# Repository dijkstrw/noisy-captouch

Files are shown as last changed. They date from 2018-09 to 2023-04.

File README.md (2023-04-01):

Noisy captouch
==============

Toggling a lamp by touching its plastic base.

This project adds capacitive touch to an IKEA Jansjo light. An MSP430 on a
custom pcb is installed in between the lamp power supply and the lamp. The
MSP430 detects touches using a sensor pad in the base of the lamp, under the
ABS cover.

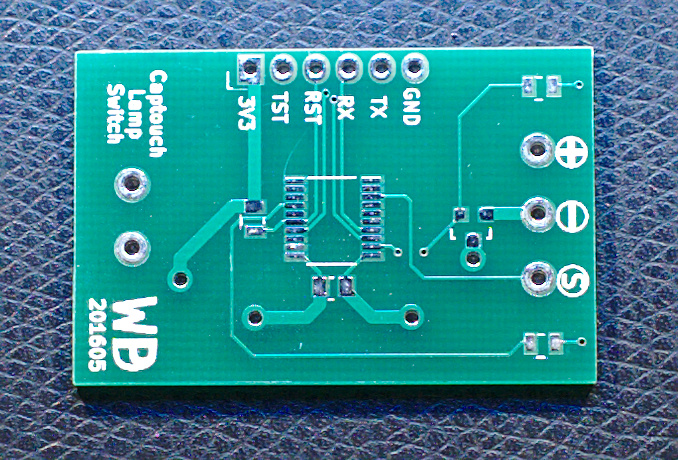
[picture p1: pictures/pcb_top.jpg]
PCB v1 Top

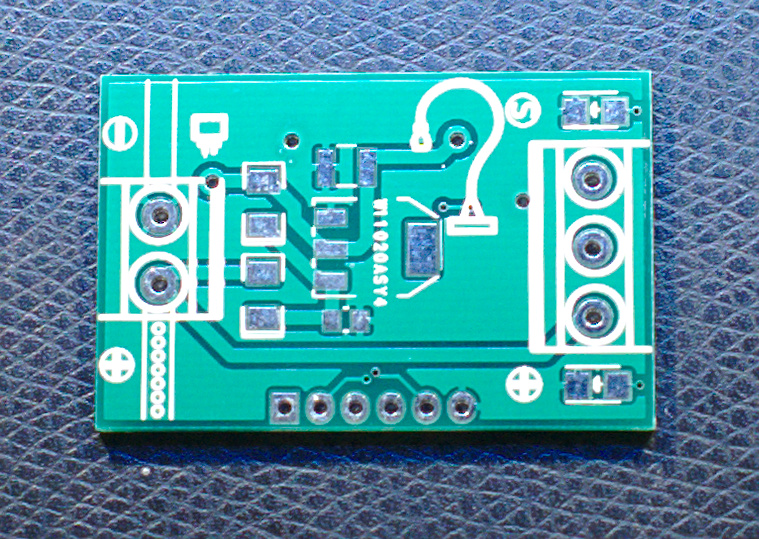
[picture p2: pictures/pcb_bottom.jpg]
PCB v1 Bottom

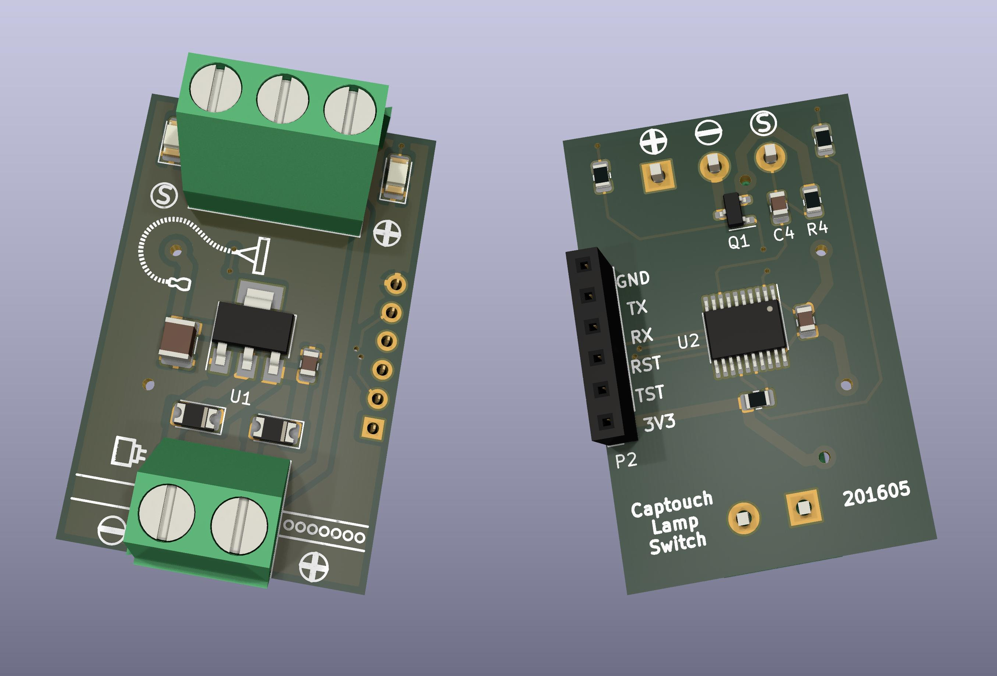
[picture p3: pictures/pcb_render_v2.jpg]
PCB v2

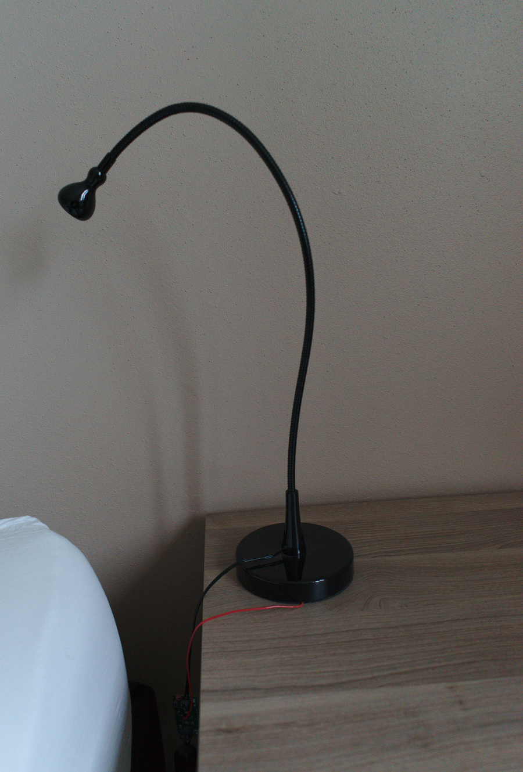
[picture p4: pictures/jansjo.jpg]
Jansjo on nightstand


Touch algorithm
---------------
The measurement happens in a number of steps:
- first we build up a sliding sample window of 16 measurements
  (sum). This also provides us with a moving average (sum/16).

- we calculate a derivative = moving average - current measurement.

- if the derivative is positive: the measurement indicates that the
  counter wrapped less times than expected; which can be an indication
  of increased capacitance due to a touch event.

- if the derivative is higher than a preset threshold (minimum
  required change) we add part of it to the integral. Note that only
  part is considered, to make sure we need multiple "positive"
  measurements in sequence before we signal a touch event.

- if the integral has reached a preset threshold we signal a touch
  event, if not, we leak away some of our integrand to make sure the
  integral reports over a recent period only.

This algorithm tries to cater for a number of things:

- Atmospheric changes will change the measured capacitance, so we must
  take measurement drift into account.

- The electrodes are very sensitive and will pickup any large enough
  emf spikes, so we cannot trust single measured capacitance changes.

- If the emf spikes are high enough almost arbitrary measurements are
  possible, so we need to limit their contribution to integrand.

Complications
-------------

1. Power for the msp430 comes from a wallwart that also feeds the
   lamp. When the lamp is off, only the msp430 is drawing
   current. When the lamp is on an additional 500mA is drawn from the
   wallwart. This transition causes unwanted powersupply noise that
   interferes with the measurements.

2. When programming and debugging the ground is connected to the
   programmer ground. The effect of point 1 can then be
   underestimated. It is best to use an usb isolator when programming.

3. There are no right values for the capacitive touch thresholds, as
   these depend on the capacitive measurement, which in turn depend on
   your touch pad geometry. Especially for home built arbitrary sized
   pads as lamp bases, the values will differ between pads.

USCI
----
By using WDT for measurement we have enough of Timer0 left to do
bitbanging serial for non-USCI MSPs. (msp430g2452).

References
----------
- [Benn Thomsen, Capacitive Touch examples, March 2016](https://github.com/bennthomsen/CapacitiveTouch)
- Brandon Elliott/D. Dang, Texas Instruments Inc., November 2010

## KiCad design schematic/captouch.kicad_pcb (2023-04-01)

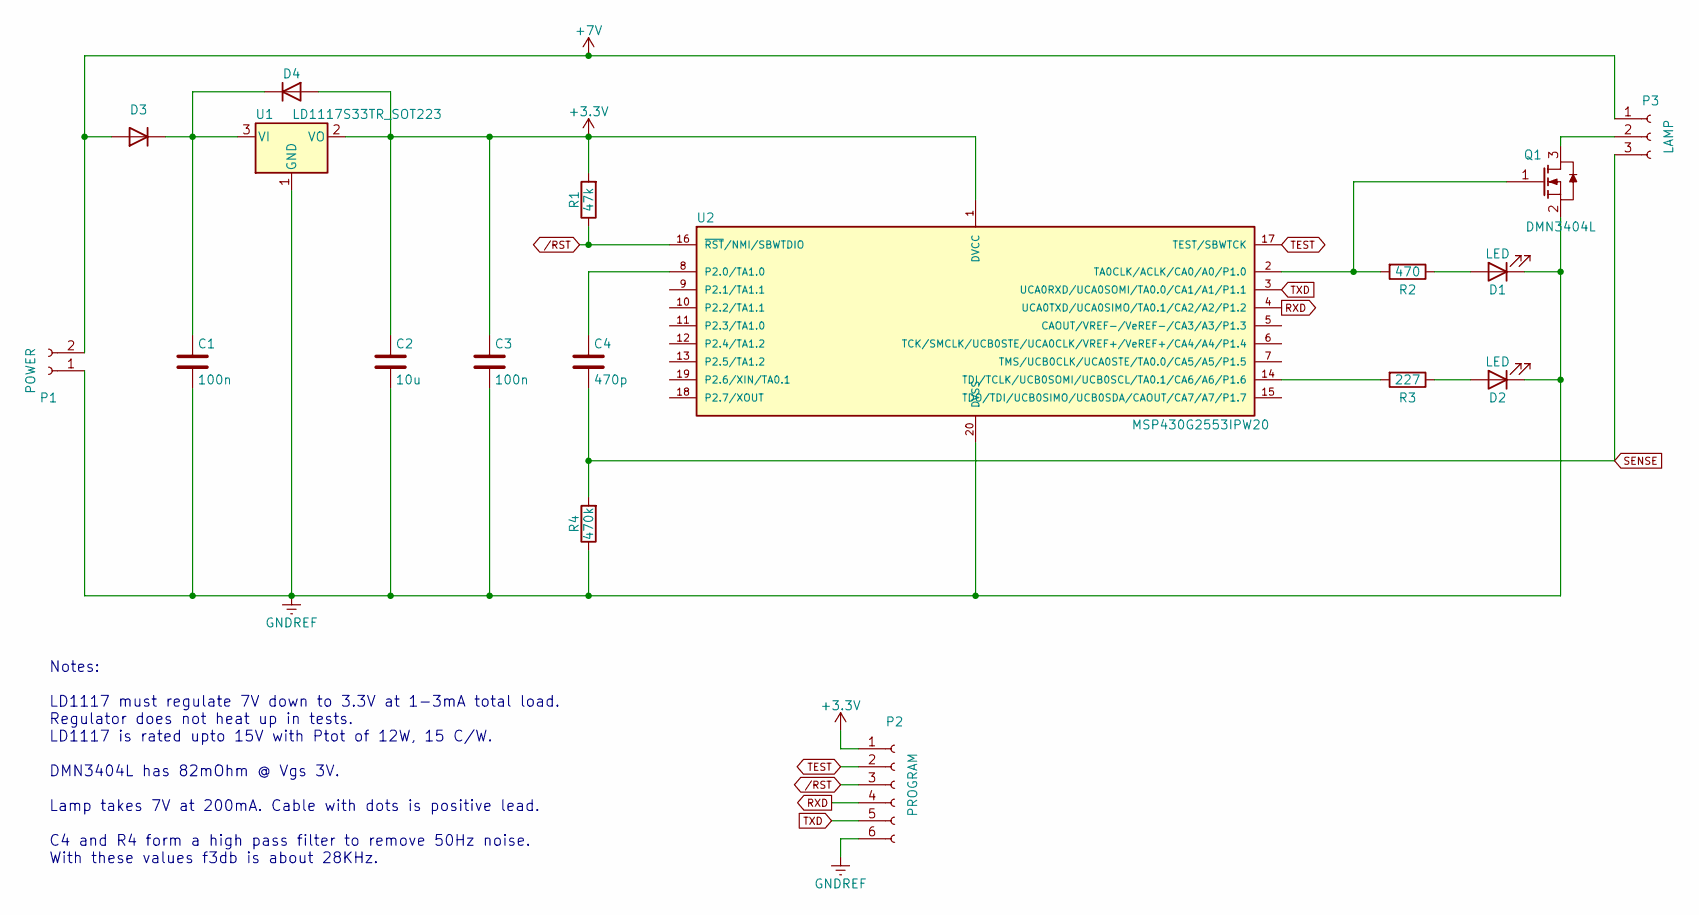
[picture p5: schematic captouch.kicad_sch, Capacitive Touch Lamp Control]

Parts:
C1, C3: 100n; C_0805
C2: 10u; C_1210
C4: 470p; C_0805
D1, D2: LED; LED_1206
D3, D4: D; SMD-1206_Pol
P1: POWER; P_1,5-2
P2: PROGRAM; Pin_Header_Angled_1x06
P3: LAMP; P_1,5-3
Q1: DMN3404L; SOT-23
R1: 47k; R_0805
R2: 470; R_0805
R3: 227; R_0805
R4: 470k; R_0805
U1: LD1117S33TR_SOT223; SOT-223-3_TabPin2
U2: MSP430G2553IPW20; TSSOP-20_4.4x6.5mm_Pitch0.65mm

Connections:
+3.3V: C2.1, C3.1, D4.2 (A), P2.1, R1.2, U1.2 (VO), U2.1 (DVCC)
+7V: D3.2 (A), P1.2, P3.1
GNDREF: C1.2, C2.2, C3.2, D1.1 (K), D2.1 (K), P1.1, P2.6, Q1.2 (S), R4.1, U1.1 (GND), U2.20 (DVSS)
unnamed: C1.1, D3.1 (K), D4.1 (K), U1.3 (VI)
unnamed: P3.2, Q1.3 (D)
unnamed: Q1.1 (G), R2.2, U2.2 (TA0CLK/ACLK/CA0/A0/P1.0)
unnamed: D1.2 (A), R2.1
unnamed: D2.2 (A), R3.1
unnamed: C4.1, U2.8 (P2.0/TA1.0)
unnamed: R3.2, U2.14 (TDI/TCLK/UCB0SOMI/UCB0SCL/TA0.1/CA6/A6/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)
RXD: P2.4, U2.4 (UCA0TXD/UCA0SIMO/TA0.1/CA2/A2/P1.2)
SENSE: C4.2, P3.3, R4.2
TEST: P2.2, U2.17 (TEST/SBWTCK)
TXD: P2.5, U2.3 (UCA0RXD/UCA0SOMI/TA0.0/CA1/A1/P1.1)
/RST: P2.3, R1.1, U2.16 (~RST/NMI/SBWTDIO)

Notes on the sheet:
Notes: LD1117 must regulate 7V down to 3.3V at 1-3mA total load. Regulator does not heat up in tests. LD1117 is rated upto 15V with Ptot of 12W, 15 C/W. DMN3404L has 82mOhm @ Vgs 3V. Lamp takes 7V at 200mA. Cable with dots is positive lead. C4 and R4 form a high pass filter to remove 50Hz noise. Wi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

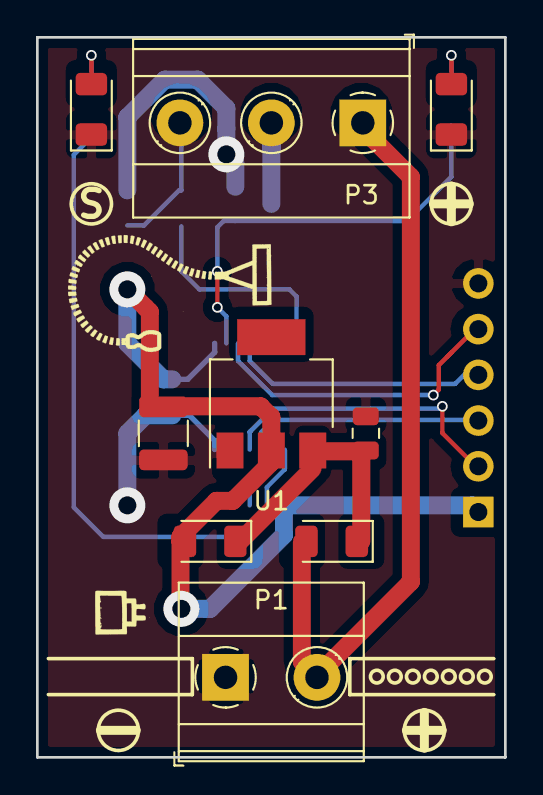
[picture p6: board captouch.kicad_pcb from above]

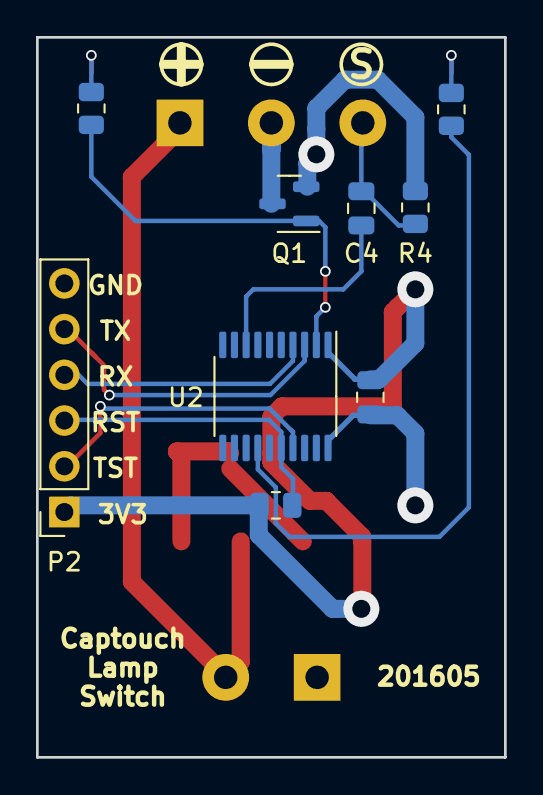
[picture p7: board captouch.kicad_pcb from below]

Board: 2 copper layers, 26.0 x 40.0 mm, 19 parts (9 on the bottom side), 15 nets.

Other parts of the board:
  : lamp

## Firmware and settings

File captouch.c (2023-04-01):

/*
 * MSP430 Capacitive Lamp Control
 *
 * Toggling a lamp by touching its plastic base.
 *
 * Description: Basic 1-button input using the built-in pin oscillation feature
 * on GPIO input structure. PinOsc signal feed into TA0CLK. WDT interval is
 * used to gate the measurements. A large difference in measurements indicate
 * button touch.
 *
 * Use an averaging window of SAMPLES as a moving baseline to compare incoming
 * "sensor" readings. This makes a large difference for touch stand out, while
 * allowing for a gradual drift to accomodate for athmospheric changes.
 *
 * ACLK = VLO = 12kHz, MCLK = SMCLK = 1MHz DCO
 *
 *               MSP430G2xxx
 *             -----------------
 *         /|\|              XIN|- UART
 *          | |                 |
 *          --|RST          XOUT|-
 *            |                 |
 *            |             P2.0|<--Capacitive Touch Input 1
 *            |                 |
 *  LED 2  <--|P1.6             |
 *  window reset indication     |
 *  LED 1  <--|P1.0             |
 *  lamp driver/indication      |
 *            |                 |
 *
 *
 * Based on source from:
 * - Benn Thomsen, March 2016
 * - Brandon Elliott/D. Dang, Texas Instruments Inc., November 2010
 */

#include <stdint.h>
#include <stdlib.h>
#include <msp430.h>
#include "captouch.h"
#include "uart.h"
#include "xprint.h"

uint8_t lamp;
uint8_t state;

uint16_t loops = 0;
int16_t on_timer = 0;
window_t window;

uint16_t
measure(uint8_t pin)
{
    uint16_t result;

    /* Ground the input */
    P2SEL &= ~pin;
    P2DIR &= ~pin;
    P2OUT &= ~pin;
    P2REN |= pin;
    P2REN &= ~pin;

    WDTCTL = WDT_GROUND_INTERVAL;
    _BIS_SR(LPM0_bits + GIE);

    /* Configure timer to capture oscillator */
    TA0CTL = TASSEL_3 + MC_2;           /* INCLK from Pin oscillator, continous count mode to 0xFFFF */
    TA0CCTL1 = CM_3 + CCIS_2 + CAP;     /* Capture on Rising and Falling Edge,Capture input GND,Capture mode */

    /*
     * Configure Ports for relaxation oscillator
     * P2SEL2 allows Timer_A to receive it's clock from a GPIO
     */
    P2DIR &= ~pin;
    P2SEL &= ~pin;
    P2SEL2 |= pin;

    /* Setup Gate Timer */
    WDTCTL = WDT_MEASURE_INTERVAL;
    TA0CTL |= TACLR;                    /* Reset timer */
    _BIS_SR(LPM0_bits + GIE);
    TA0CCTL1 ^= CCIS0;                  /* Toggle the counter capture input to capture count using TACCR1 */
    result = TACCR1;
    P2SEL2 &= ~pin;                     /* Disable Oscillator */

    WDTCTL = WDTPW + WDTHOLD;
    /* Ground the input */
    P2SEL &= ~pin;
    P2DIR &= ~pin;
    P2OUT &= ~pin;
    P2REN |= pin;
    P2REN &= ~pin;

    return result;
}

uint8_t
detect()
{
    uint16_t measurement = measure(TOUCH_PIN);

    /*
     * Keep track of how many measurements we have between emitting
     * state
     */
    window.times = window.times + 1;

    /*
     * Look at the amount of change
     */
    window.derivative = window.avg - measurement;

    /*
     * An increase of capacitance means that less full counts of the
     * oscillator will be counted; so a touch => a positive
     * derivative
     */
    if (window.derivative > DERIVATIVE_THRESHOLD) {
        window.integral += DERIVATIVE_THRESHOLD;
    } else {
        /*
         * Make current measurement part of the moving average
         */
        window.sum -= window.data[window.index];
        window.data[window.index] = measurement;
        window.sum += window.data[window.index];
        window.index = (window.index + 1 ) % SAMPLES;

        window.avg = window.sum >> SAMPLES_DIV;
    }

    /*
     * Now look at the accumulated change
     */
    if (window.integral > INTEGRAL_THRESHOLD) {
        emit_state();
        window.integral = 0;
        return 1;
    } else {
        /* No touch -- leak away some of our integrand */
        if (window.integral > LEAKAGE_FACTOR) {
            window.integral -= LEAKAGE_FACTOR;
        } else {
            window.integral = 0;
        }

        return 0;
    }
}

void
emit_state(void)
{
    xprintf("S%01x p%01x o%04x D%04x I%04x A%04x S%04x%04x t%04x \r\n",
            state,
            lamp,
            on_timer,
            window.derivative,
            window.integral,
            window.avg,
            (uint16_t )(window.sum >> 16),
            (uint16_t)(window.sum & 0xFFFF),
            window.times);
    window.times = 0;
}

void
lamp_off(void)
{
    LED_OUT &= ~LAMP_PIN;
    lamp = 0;
    emit_state();
}

void
lamp_on(void)
{
    LED_OUT |= LAMP_PIN;
    lamp = 1;
    emit_state();
}

void
reset_window()
{
    window.sum = window.derivative = window.integral = 0;

    for (window.index = 0; window.index < SAMPLES; window.index++) {
        window.data[window.index] = measure(TOUCH_PIN);
        window.sum += window.data[window.index];
        xprintf("Reset window %02x: S%04x%04x \r\n",
                window.index,
                (uint16_t )(window.sum >> 16),
                (uint16_t)(window.sum & 0xFFFF));
    }
    window.times = 0;
    window.avg = window.sum >> SAMPLES_DIV;
}

int
main(void)
{
    uint8_t touch;

    WDTCTL = WDTPW + WDTHOLD;    /* Stop WDT */
    DCOCTL = 0;                  /* Select lowest DCOx and MODx settings */
    BCSCTL1 = CALBC1_1MHZ;       /* Set DCO to 1MHz */
    DCOCTL = CALDCO_1MHZ;
    BCSCTL3 |= LFXT1S_2;         /* LFXT1 = VLO 12kHz */

    IE1 |= WDTIE;

    LED_DIR |= (LAMP_PIN + BOOT_PIN);
    LED_OUT &= ~(LAMP_PIN + BOOT_PIN);

    uart_configure();
    _BIS_SR(GIE);
    __no_operation();

    lamp = 0;
    reset_window();
    state = LAMP_RESET;

    for (;;) { /* FOREVER */
        touch = detect();

        switch (state) {
        case LAMP_RESET:
            /* 0. After boot and after a change, take one second to settle */
            LED_OUT |= BOOT_PIN;
            loops++;
            if (loops > LOOPS_1S) {
                LED_OUT &= ~BOOT_PIN;
                loops -= LOOPS_1S;
                state = LAMP_IDLE;
                reset_window();
                emit_state();
            }
            break;

        case LAMP_IDLE:
            /* 1. In idle, countdown on time or "detect" touch */
            if (lamp) {
                if (on_timer > 0) {
                    loops++;
                    while (loops > LOOPS_1S) {
                        loops -= LOOPS_1S;
                        on_timer--;
                        emit_state();
                    }
                } else {
                    lamp_off();
                }
            } else {
                on_timer = 0;
            }

            if (touch) {
                state = LAMP_ACTION;
            }
            break;

        case LAMP_ACTION:
            /* 2. Change lamp state and revert to RESET */
            lamp ^=1;
            if (lamp) {
                lamp_on();
                on_timer = AUTO_OFF_S;
            } else {
                lamp_off();
                on_timer = 0;
            }
            state = LAMP_RESET;
            loops = 0;
            break;
        }

        WDTCTL = WDT_DELAY_INTERVAL;
        LPM3;
    }
}

void __attribute__((interrupt(WDT_VECTOR))) watchdog_timer(void)
{
    LPM3_EXIT;
}

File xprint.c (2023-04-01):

/*
 * MSP430 minimal xprintf
 *
 * Based on mini-printf:
 * Copyright (c) 2013,2014 Michal Ludvig <michal@logix.cz>
 * All rights reserved.
 *
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
 * THIS SOFTWARE IS PROVIDED BY THE COPYRIGHT HOLDERS AND CONTRIBUTORS "AS IS" AND
 * ANY EXPRESS OR IMPLIED WARRANTIES, INCLUDING, BUT NOT LIMITED TO, THE IMPLIED
 * WARRANTIES OF MERCHANTABILITY AND FITNESS FOR A PARTICULAR PURPOSE ARE
 * DISCLAIMED. IN NO EVENT SHALL THE AUTHOR BE LIABLE FOR ANY
 * DIRECT, INDIRECT, INCIDENTAL, SPECIAL, EXEMPLARY, OR CONSEQUENTIAL DAMAGES
 * (INCLUDING, BUT NOT LIMITED TO, PROCUREMENT OF SUBSTITUTE GOODS OR SERVICES;
 * LOSS OF USE, DATA, OR PROFITS; OR BUSINESS INTERRUPTION) HOWEVER CAUSED AND
 * ON ANY THEORY OF LIABILITY, WHETHER IN CONTRACT, STRICT LIABILITY, OR TORT
 * (INCLUDING NEGLIGENCE OR OTHERWISE) ARISING IN ANY WAY OUT OF THE USE OF THIS
 * SOFTWARE, EVEN IF ADVISED OF THE POSSIBILITY OF SUCH DAMAGE.
 */
#include <stdint.h>
#include "uart.h"
#include "xprint.h"

static uint8_t
itoa(int16_t value, uint16_t radix, uint16_t uppercase, uint16_t unsig,
          char *buffer, uint16_t zero_pad)
{
    char *pbuffer = buffer;
    int16_t negative = 0;
    uint16_t i, len;

    /* No support for unusual radixes. */
    if (radix > 16)
        return 0;

    if (value < 0 && !unsig) {
        negative = 1;
        value = -value;
    }

    /* This builds the string back to front ... */
    do {
        int digit = value % radix;
        *(pbuffer++) = (digit < 10 ? '0' + digit : (uppercase ? 'A' : 'a') + digit - 10);
        value /= radix;
    } while (value > 0);

    for (i = (pbuffer - buffer); i < zero_pad; i++)
        *(pbuffer++) = '0';

    if (negative)
        *(pbuffer++) = '-';

    *(pbuffer) = '\0';

    /* ... now we reverse it (could do it recursively but will
     * conserve the stack space) */
    len = (pbuffer - buffer);
    for (i = 0; i < len / 2; i++) {
        char j = buffer[i];
        buffer[i] = buffer[len-i-1];
        buffer[len-i-1] = j;
    }

    return len;
}

static void
xvprintf(const char *fmt, va_list va)
{
    char bf[12];
    char ch;

    while ((ch = *(fmt++))) {
        if (ch == '\n') {
            uart_putc('\n');
            uart_putc('\r');
        } else if (ch != '%') {
            uart_putc(ch);
        } else {
            char zero_pad = 0;
            char *ptr;
            uint8_t len;

            ch = *(fmt++);

            /* Zero padding requested */
            if (ch == '0') {
                ch = *(fmt++);
                if (ch == '\0')
                    return;
                if (ch >= '0' && ch <= '9')
                    zero_pad = ch - '0';
                ch = *(fmt++);
            }

            switch (ch) {
            case 0:
                return;

            case 'u':
            case 'd':
                len = itoa(va_arg(va, unsigned int), 10, 0, (ch == 'u'), bf, zero_pad);
                uart_send_array((uint8_t *)bf, len);
                break;

            case 'x':
            case 'X':
                len = itoa(va_arg(va, unsigned int), 16, (ch == 'X'), 1, bf, zero_pad);
                uart_send_array((uint8_t *)bf, len);
                break;

            case 'c' :
                uart_putc((char)(va_arg(va, int)));
                break;

            case 's' :
                ptr = va_arg(va, char*);
                uart_send_string((uint8_t *)ptr);
                break;

            default:
                uart_putc(ch);
                break;
            }
        }
    }
}


void
xprintf(const char *fmt, ...)
{
    va_list va;

    va_start(va, fmt);
    xvprintf(fmt, va);
    va_end(va);
}

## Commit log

2018-08-04 Source from github slightly modified for my sensor
2018-08-04 Added schematic, started pcb
    [captouch.kicad_pcb, captouch.sch]
2018-08-04 Added better heuristics at turnon
    Measurement is now faster at expense of more power. Green led turns on
    at powerup to show the user that we are calibrating. Measurement now
    runs longer to enable a better read + a higher level is now needed to
    turn on. Also turn on/off time is faster.
2018-08-04 Started layout
    [captouch.kicad_pcb]
2018-08-04 Finished routing
    Artwork is next
    [captouch.kicad_pcb]
2018-08-04 Added logos
    [captouch.kicad_pcb]
2018-08-04 Incorporated Martins schematic comments
    [captouch.kicad_pcb, captouch.sch]
2018-08-04 Updated uart source for correct tx/rx mapping
    [uart.c]
2018-08-04 More little adjustments + logo
    [captouch.kicad_pcb, captouch.sch]
2018-08-04 Added auto timer off
2018-08-04 Rev 1, as fabbed by pcbway
    [captouch-B.Cu.gbr, captouch-B.Mask.gbr, captouch-B.SilkS.gbr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]
2018-08-04 Archived footprints, rev 2 schematic
    Fet footprint was wrong. Fixed in this schematic.
    [captouch.kicad_pcb]
2018-08-04 Added high pass filter
    [captouch.kicad_pcb, captouch.sch]
2018-08-04 Allow measurement window to drift + reset when keyed
    Measurement window can now drift slowly up and down, to account for
    environmental changes. A state machine that was present before but not
    explicit replaces the spaghetti ifs that came before. At key, the
    measurement window is reset to ensure that we know the current average
    measurement and are able to respond to change.
    We know that a person's touch would increase the capacitance, and thus
    that when we are keyed, we expect our measurement to be less (not more)
    than the average. This makes us sensitive to keys "press", but not to
    "release".
    [captouch.c, captouch.h]
2023-04-01 Adjust touch algorithm to take atmospheric drift into account
    [captouch.c, captouch.h]
2023-04-01 Sense algorithm now requires consecutive touching
    The sense algorithm now detects large changes in capacitance, and
    requires several large changes over time before it will signal a
    touch.
    There are a number of moving parts: a moving average, a derivative and
    and integral.
    - We take the average over the last 16 measurements, taking only those
    measurements that have relative small drift. This way we take
    atmospheric drift into account.
    - We determine touch by taking the difference of the current
    measurement with respect to the known relatively stable average (this
    could be seen as the rate of change, i.e. the derivative of
    capacitance change)
    - If the derivative is more than DERI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
    [captouch.c, captouch.h]
2023-04-01 Update schematic to kicad 6
    I wanted renders of the schematics, so adjusted all components to
    kicad standard components. This way we also get to the associated 3d
    models.
    [captouch-B.Cu.gbr, captouch-B.Mask.gbr, captouch-B.SilkS.gbr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]
2023-04-01 Update readme
    - With latest render of v2 pcb
    - With more information about the algorithm
    - Remove old measurements information
